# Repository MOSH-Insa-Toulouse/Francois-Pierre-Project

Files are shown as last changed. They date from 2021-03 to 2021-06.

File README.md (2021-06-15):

# Francois-Pierre-Project
## Projet capteur graphene
Projet de 4ème année Génie Physique, à l'INSA de Toulouse. Réalisation d'un capteur graphene de déformation. Le but est de mesurer la résistance et la tension du graphene sur une feuille de papier. Pour ce faire nous avons élaborer un capteur accessible à tous et simple d'utilisation sur arduino et App Inventor. Dans ce Git vous trouverez toute les ressources et information nécessaire pour comprendre le fonctionnement de notre capteur et pouvoir le réaliser chez vous.

## Sommaire

  - [1. Matériel requis](#1-Matériel-requis)
  - [2. Kicad](#2-Kicad)
      - [2.1 Création des empreintes et des composants](#21-Création-des-empreintes-et-des-composants)
      - [2.2 Création du PCB](#22-Création-du-PCB)
  - [3. Code Arduino](#3-code-arduino)
      - [3.1 Librairies utilisées](#31-Librairies-utilisées)
      - [3.2 Le code](#32-Le-code)
  - [4. Application Bluetooth](#4-application-Bluetooth)
  - [5. Banc de test](#5-Banc-de-test)
      - [5.1 Fonctionnement du banc](#51-Fonctionnement-du-banc)
      - [5.2 Code arduino](#52-Code-arduino)
  - [6. Datasheet](#6-datasheet)
  - [7. Contacte](#6-Contacte)

## 1. Matériel requis  

- Smartphone Androide 
- Carte Arduino Uno [info](https://www.arduino-france.com/review/arduino-uno/)
- Une plaque de cuivre pour shield. Ou bien des câbles de connexions
- Papier
- Crayon de papier
- Un module HC-05 (gestion du Bluetooth) [ici](https://fr.aliexpress.com/item/32496218488.html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)
- Un écran OLED [ici](https://www.google.com/aclk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)
- Un encodeur rotatif [ici](https://www.google.com/aclk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)
- Deux pince crocodile en cuivre
- Un transistor LTC1050 [ici](https://www.reichelt.com/fr/fr/amplificateurs-op-rationnels-unique-2-5-mhz-dil-8-ltc-1050-cn8-p10921.html) 

## 2. Kicad 

Kicad est un logiciel de conception pour l'électronique. Il permet de créer des schémas de circuit, visualiser des circuits en 3D, associer des empreintes au circuit. Dans notre cas, nous utilisons Kicad pour créer un shield pour notre carte Arduino Uno. Ce shield va nous permettre de monter nos composant directement sur la carte. Toute nos empreintes et plans de notre shield sont disponible dans [notre GIT](https://github.com/MOSH-Insa-Toulouse/Francois-Pierre-Project/tree/main/Shield)  

### 2.1 Création des empreintes et des composants

- Pour réaliser notre shield, nous avons dû créer une librairie d'empreinte pour nos composants. En effet ceux-ci n'étant pas disponible sur les librairies de Kicad nous avons donc créés des schémas et empreintes pour tous nos modules.

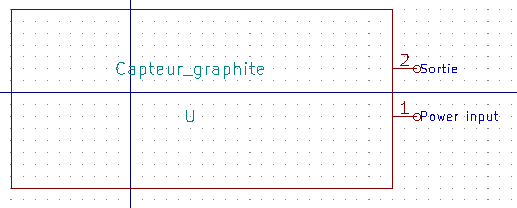
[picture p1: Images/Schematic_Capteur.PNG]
Capteur

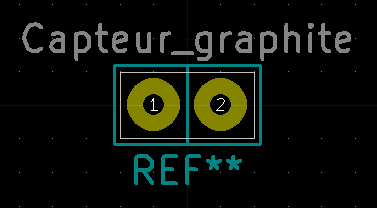
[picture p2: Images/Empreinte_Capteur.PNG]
Capteur

- *Capteur Graphite*

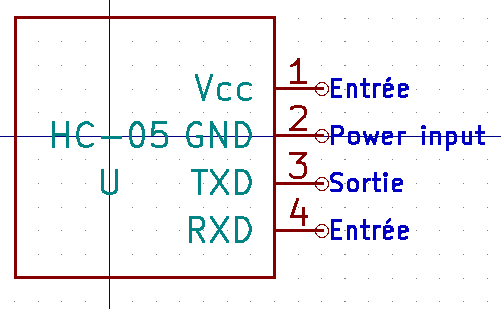
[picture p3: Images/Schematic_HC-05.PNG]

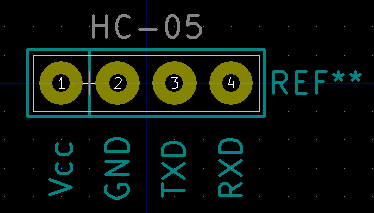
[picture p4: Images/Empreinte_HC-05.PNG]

- *HC-05*

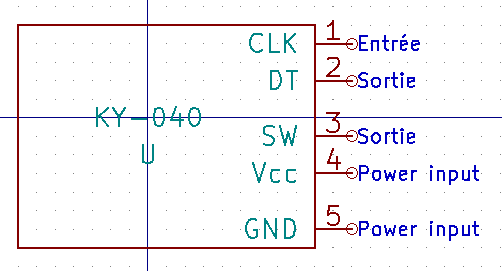
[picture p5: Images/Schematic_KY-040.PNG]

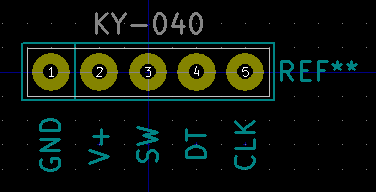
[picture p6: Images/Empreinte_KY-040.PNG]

- *Encodeur Rotatoire*

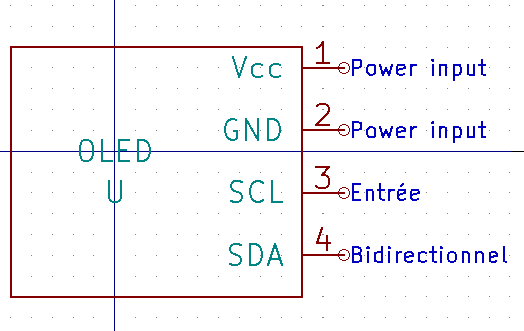
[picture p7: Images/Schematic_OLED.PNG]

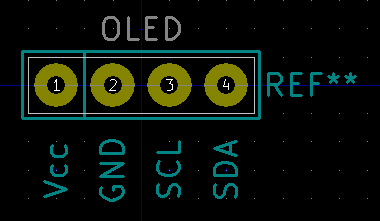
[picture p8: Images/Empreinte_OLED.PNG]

- *OLED*

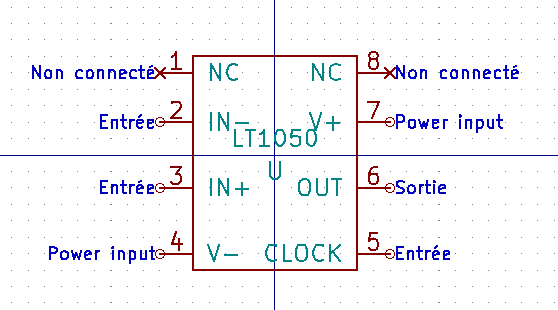
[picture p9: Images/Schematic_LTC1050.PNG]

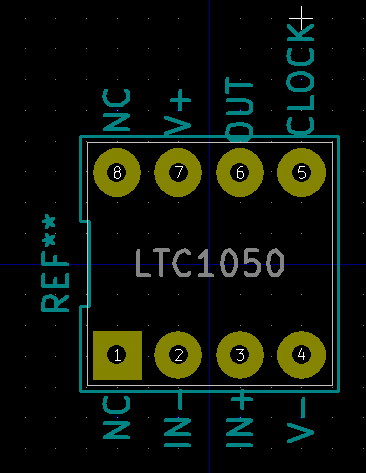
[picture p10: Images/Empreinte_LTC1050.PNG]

- *LTC1050*

### 2.2 Création du PCB

- Une fois les empreintes et les schématiques crées nous avons pu réaliser la schématique complète du circuit. Dans ce schéma vous pouvez retrouver nos modules ainsi que des composants éléctronique de base.

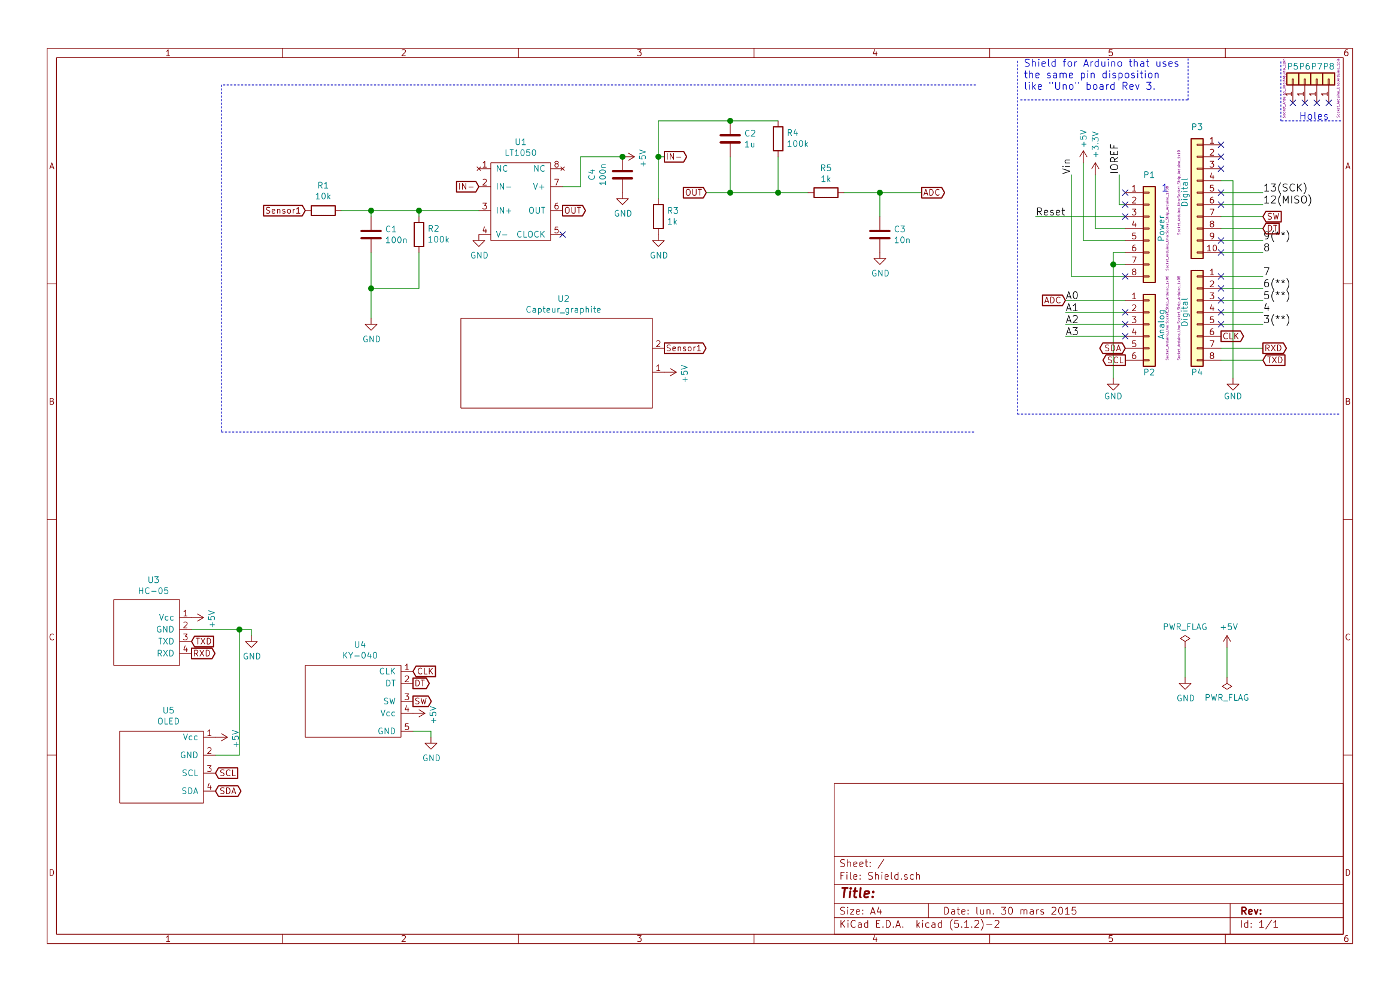
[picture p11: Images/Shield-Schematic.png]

- *Schéma de notre circuit*

- Une fois la schématique finis nous avons pu allouer à chaque composants (résistance, capacité...) une empreinte. Nous avons ensuite visualisé sur l'éditeur de circuit imprimé notre PCB. Nous avons donc organisé nos composant pour qu'il tiennent sur le shield et que nous puissons router correctement et sur chaque pin les différents modules.

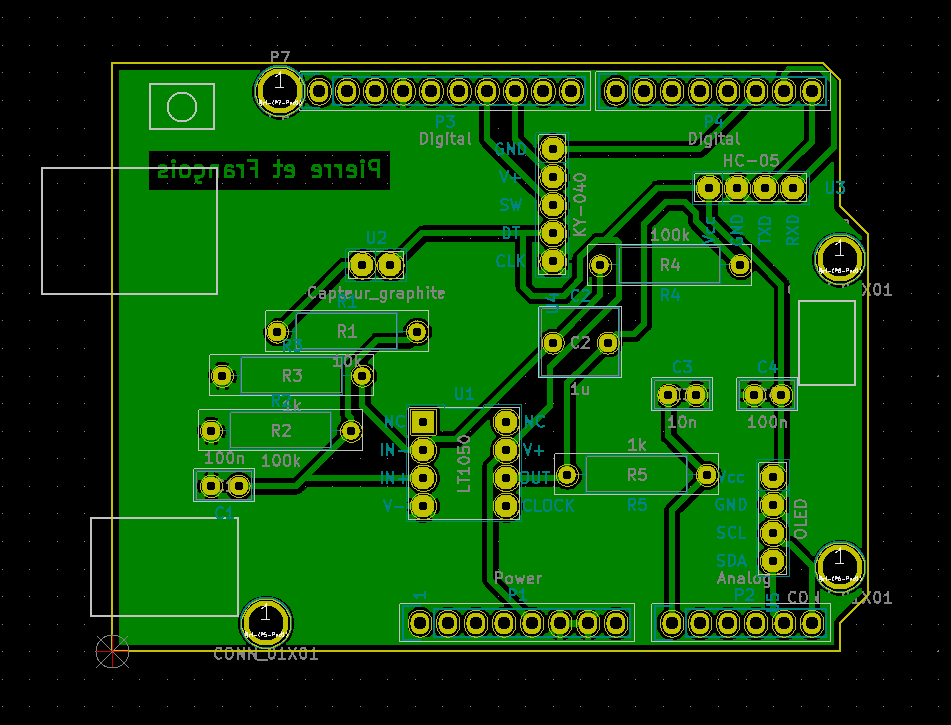
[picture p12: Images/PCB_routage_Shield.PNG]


- Pour être sur du résultat que nous voulions nous avons pu visulaiser sur Gerber notre shield en 3D avec les composant dessus, à l'execption des module bluetooth, de l'encodeur, du capteur et du LTC qui n'ont pas d'empreinte 3D.

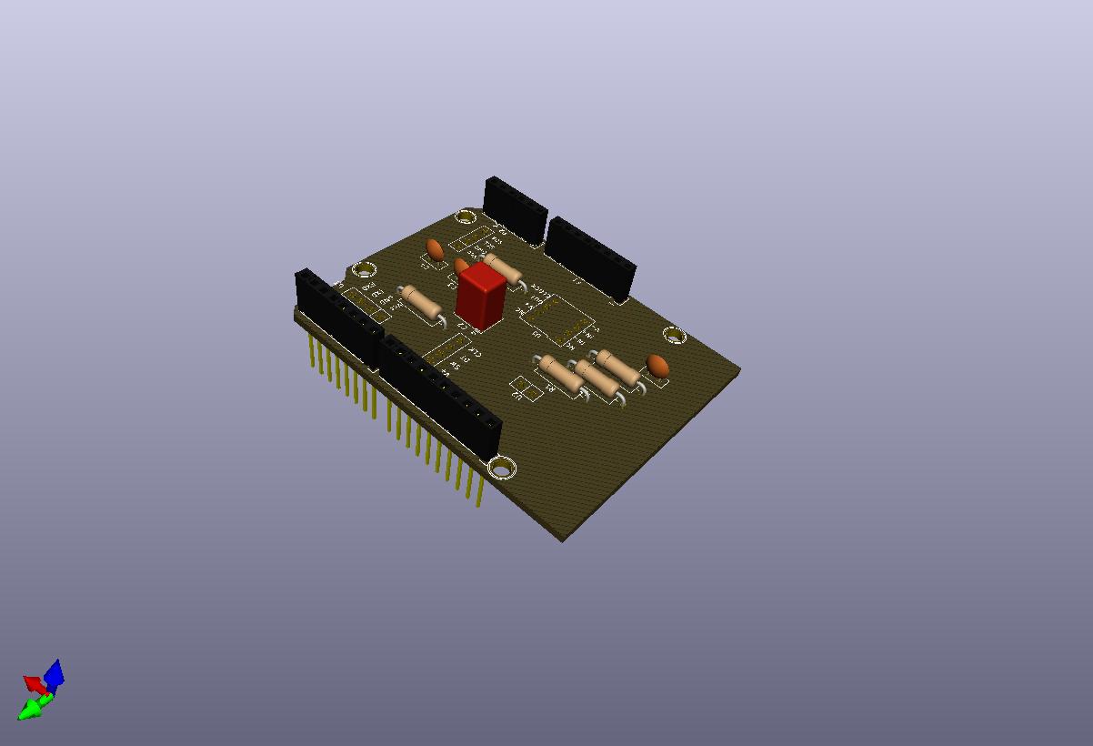
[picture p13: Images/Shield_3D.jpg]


## 3. Code Arduino

### 3.1 Librairies utilisées

- Pour réaliser notre capteur, nous utilisons [trois librairies](https://github.com/MOSH-Insa-Toulouse/Francois-Pierre-Project/tree/main/Libairies%20Arduino). 
- La librairie ["Adafruit_BusIO"](https://github.com/MOSH-Insa-Toulouse/Francois-Pierre-Project/tree/main/Libairies%20Arduino/Adafruit_BusIO) qui permet de gérer le connexions en I2C et SPI
- Les librairies ["Adafruit_GFX_Library"](https://github.com/MOSH-Insa-Toulouse/Francois-Pierre-Project/tree/main/Libairies%20Arduino/Adafruit_GFX_Library) et ["Adafruit_SSD1306"](https://github.com/MOSH-Insa-Toulouse/Francois-Pierre-Project/tree/main/Libairies%20Arduino/Adafruit_SSD1306)qui permet de gérer notre écran OLED.

### 3.2 Le code

- [Le code arduino](https://github.com/MOSH-Insa-Toulouse/Francois-Pierre-Project/tree/main/Code-Capteur-Graphite) permet de gérer le capteur. Il récupère sur le pin analogique A0 la valeur de la tension du capteur. Grace à une analyse du circuit électronique, nous pouvons déterminer la résistance en fonction de cette tension. Le code affiche sur un écran OLED différents menus en fonction de si l'on appuie ou non sur l'encodeur rotatoire. Il y a un delay de 5ms entre chaque lecture analogique.

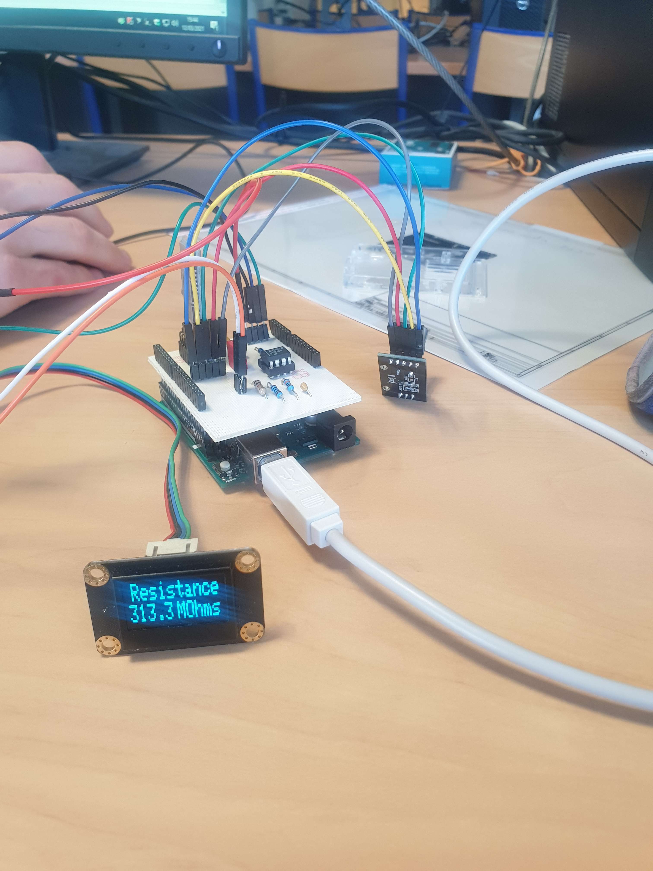
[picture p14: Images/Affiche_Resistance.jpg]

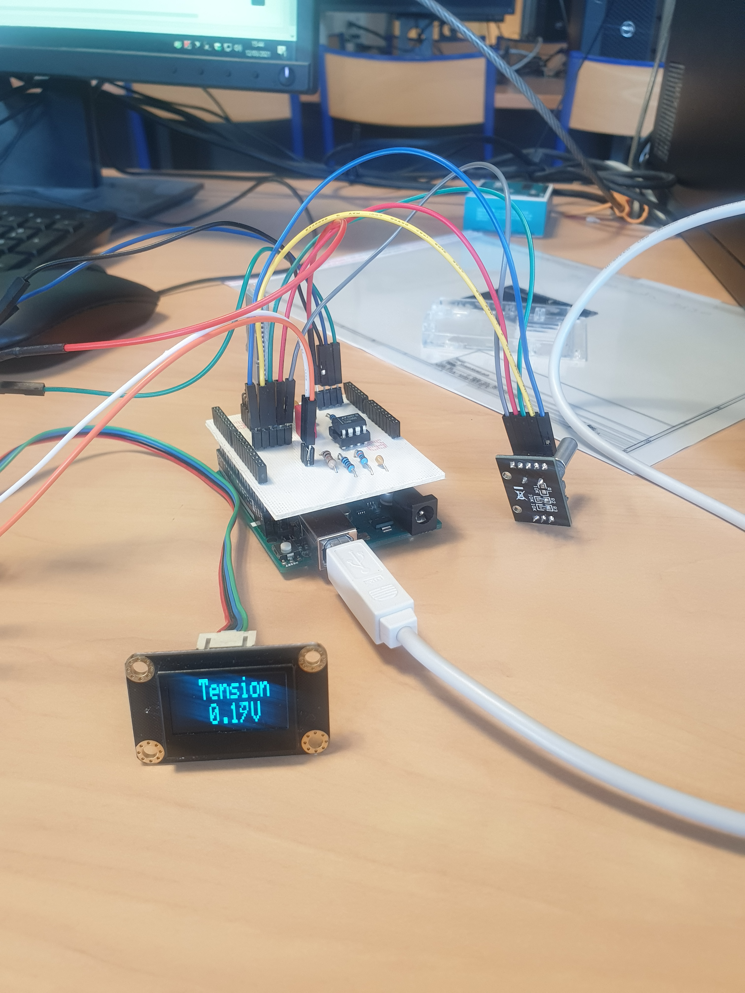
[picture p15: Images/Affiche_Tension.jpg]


## 4. Application Bluetooth

- [L'application](https://github.com/MOSH-Insa-Toulouse/Francois-Pierre-Project/blob/main/TP5.apk) permet de recevoir sur le téléphone la mesure de la résistance et de la tension délivré par le capteur. Nous affichons les deux donnés et nous traçons un graphique de la variation de résistance avec une échelle ajustable. La carte Arduino et plus précisément le module Bluetooth envoie un octet de donnée au téléphone via les pins TX et RX. Cet octet contient à la fois des valeurs de résistance et de tension séparés par de ",". Chaque doublet de valeurs est lui séparé par des ";". Notre téléphone reçois donc "49,0.39;35,0.60;70,0.37" avec d'abord la valeur de résistance puis une valeur de tension. Le téléphone sépare donc chaque valeur et les affiches. Notre application traite les données sur un intervalle de 100ms. 

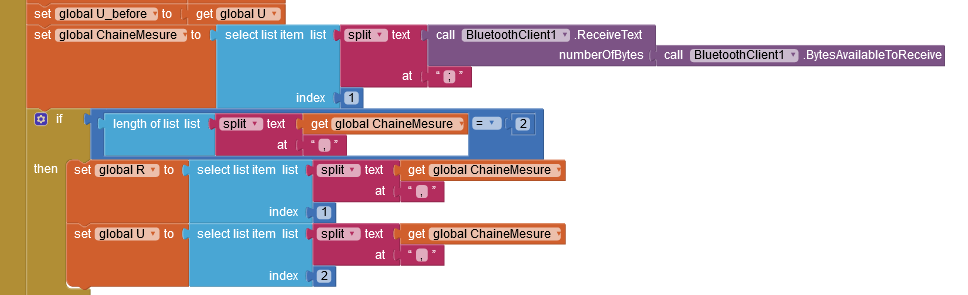
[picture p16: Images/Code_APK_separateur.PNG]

- *Code de l'application qui permet de séparer l'octet reçu et de séparer tension et résistance*

- Notre code a aussi une fonctionnalité qui enlève les variations trop importantes de résistance. En effet lors de nos tests notre téléphone recevait bien les valeurs affichées par le OLED, seulement nous avions aussi des valeurs intempestives qui ne correspondaient pas à une mesure (entre 1 et 9). Pour pallier ce problème, nous avons donc décider de ne pas prendre en compte les variations trop importantes.

- Pour finir nous avons rajouté une fonctionnalité qui permet à l'utilisateur de zoomer ou dezoomer sur le graphique.
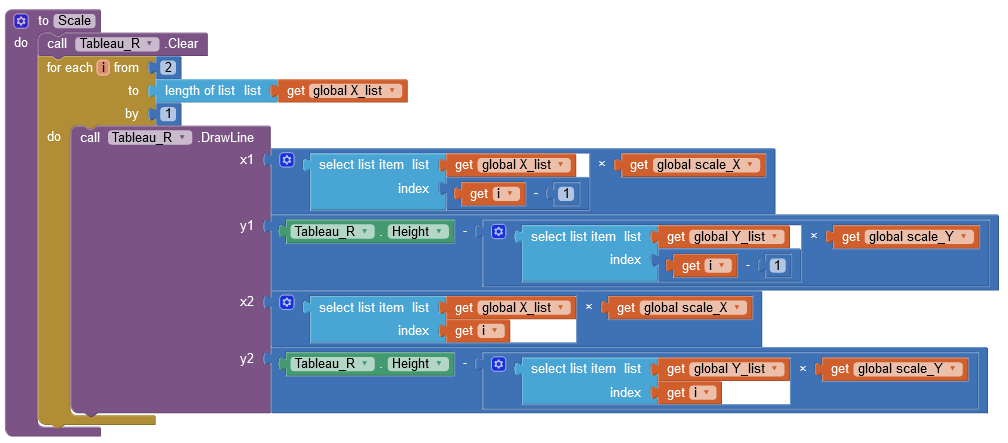
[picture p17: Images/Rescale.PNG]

- *Code APK permettant de Rescale le graphique*

- La face avant de notre application permet de choisir un module Bluetooth auquel se connecter (Cadre rouge), puis de régler l'échelle (bleu), de visualiser la variation de résistance (marron), et d'avoir les valeurs de résistance et tension en temps réelle (vert).
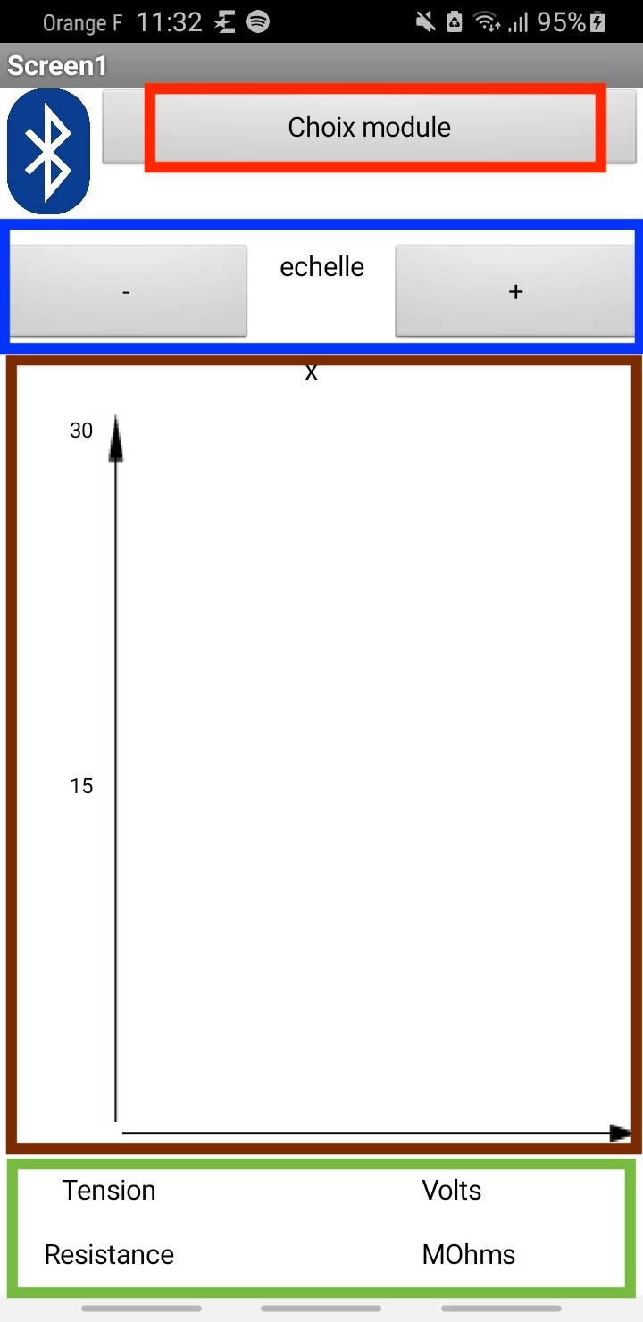
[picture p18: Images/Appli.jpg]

- *Face avant de notre application*

## 5. Banc de test

- Le banc de test est réalisé sur le logiciel de CAO FreeCad. Il nous est utile pour remplacer le banc de test initiale qui endommage et plie de manière irréversible la jauge de graphite. Le banc de test que nous avons imaginé permettrait donc de ré utiliser la même jauge plusieurs fois car celle-ci ne serait pas endommagé par les tests. Les fichier stl pour impression 3D sont [ici](https://github.com/MOSH-Insa-Toulouse/Francois-Pierre-Project/tree/main/Banc%20de%20test).

### 5.1 Fonctionnement du banc

- Le banc de test que nous avons imaginé permet de mesurer la déformation du capteur sans avoir à le toucher. Il est constitué de deux partie, le socle et la barre. Le servomoteur vient se positionner dans l'extrusion de la barre. Le disque présent sur l'autre côté vient lui se placer dans l'encoche du socle. Les pince crocodile ainsi que la jauge sont immobile grâce à l'encadrement dans lequel ils viennent s'insérer. Le servomoteur vient donc faire tourner la barre de bas en haut et nous récupérons les valeurs de résistances sur le terminal ou dans le fichier txt de notre téléphone.

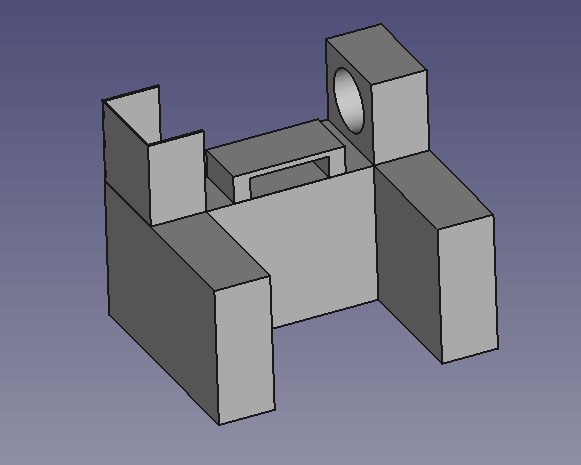
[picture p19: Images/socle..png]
- 
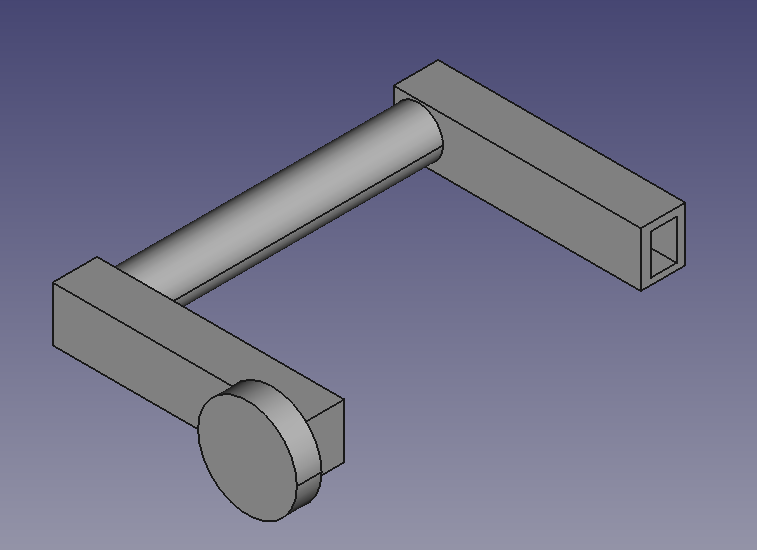
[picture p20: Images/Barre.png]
- 

- A l'inverse du banc de test initiale celui que nous avons imaginé n'a pas un rayon de courbure définis et connus. En revanche il est possible de connaitre le rayon de courbure avec la flèche F la distance S et R

### 5.2 Code arduino

- Le code arduino qui gèrent le banc de test permet d'afficher la résistance et la déformation en temps réelle. Il fait aussi s'activer le servomoteur, qui va bouger sur une rotation de 180 degrés. Cela nous permet de plier la jauge dans les deux sens. Étant donné que dans notre cas nous ne connaissons pas le rayon de courbure nous devons le calculer. Ceci est possible celons la manière suivante : 

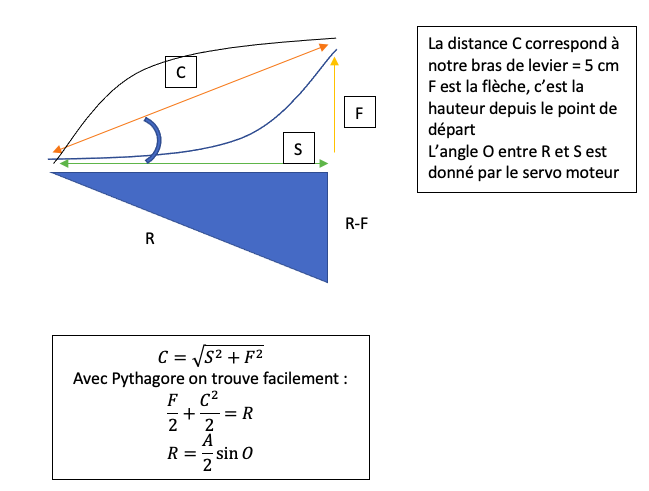
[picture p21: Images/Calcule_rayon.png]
- 

## 6. Datasheet

- [La datasheet](https://github.com/MOSH-Insa-Toulouse/Francois-Pierre-Project/blob/main/Datasheet.pdf) rédigé permet de comprendre les différentes caractéristiques de notre capteur. Veuillez la lire avant l'utilisation de celui-ci. 

## 7. Contacte

- Pour toute question concernant le capteur, l'application APK, le programme Arduino, le PCB ou pour tout complément d'information veuillez nous contacter par mail :
- Pierre CLARET pclaret@etud.insa-toulouse.fr
- François LEPETIT-AIMONT lepetit-@etud.insa-toulouse.fr

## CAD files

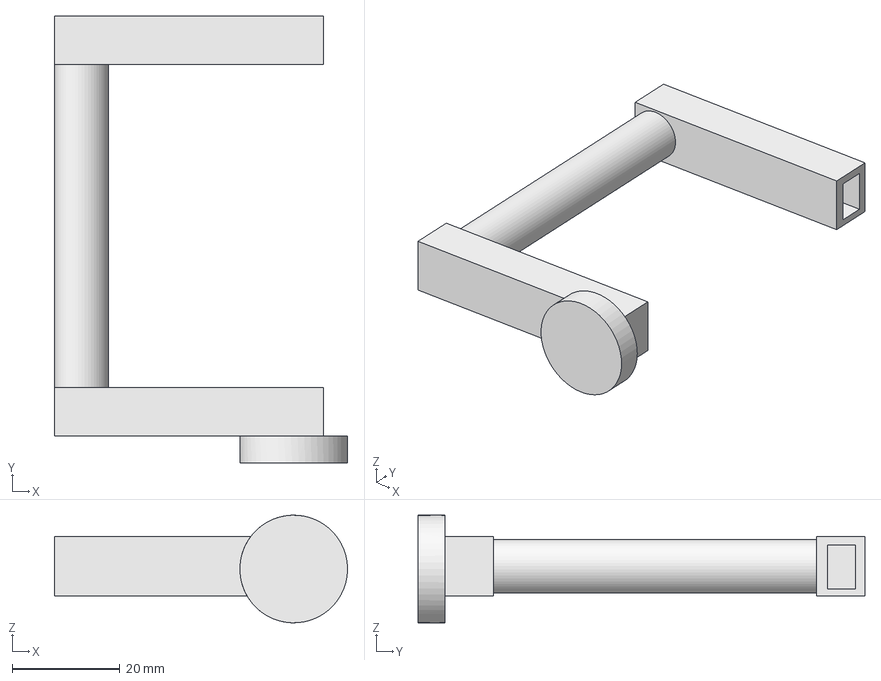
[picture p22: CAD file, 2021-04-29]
Banc de test/Barre.FCStd
54.4 x 83.0 x 20.0 mm

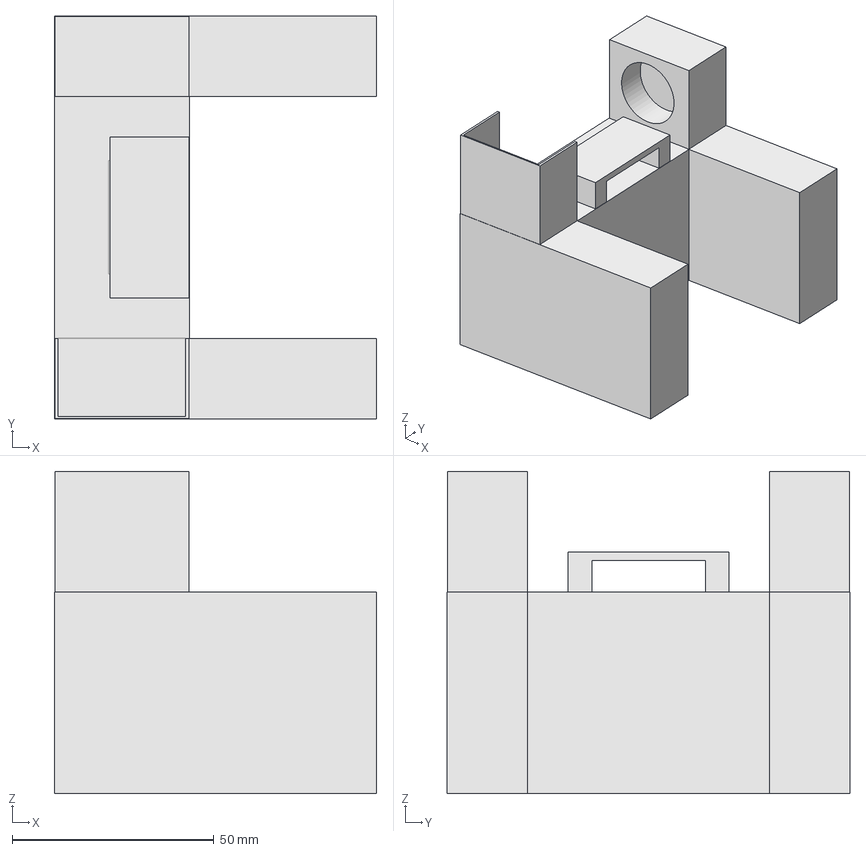
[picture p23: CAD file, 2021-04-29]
Banc de test/socle.FCStd
80.0 x 100.0 x 80.0 mm

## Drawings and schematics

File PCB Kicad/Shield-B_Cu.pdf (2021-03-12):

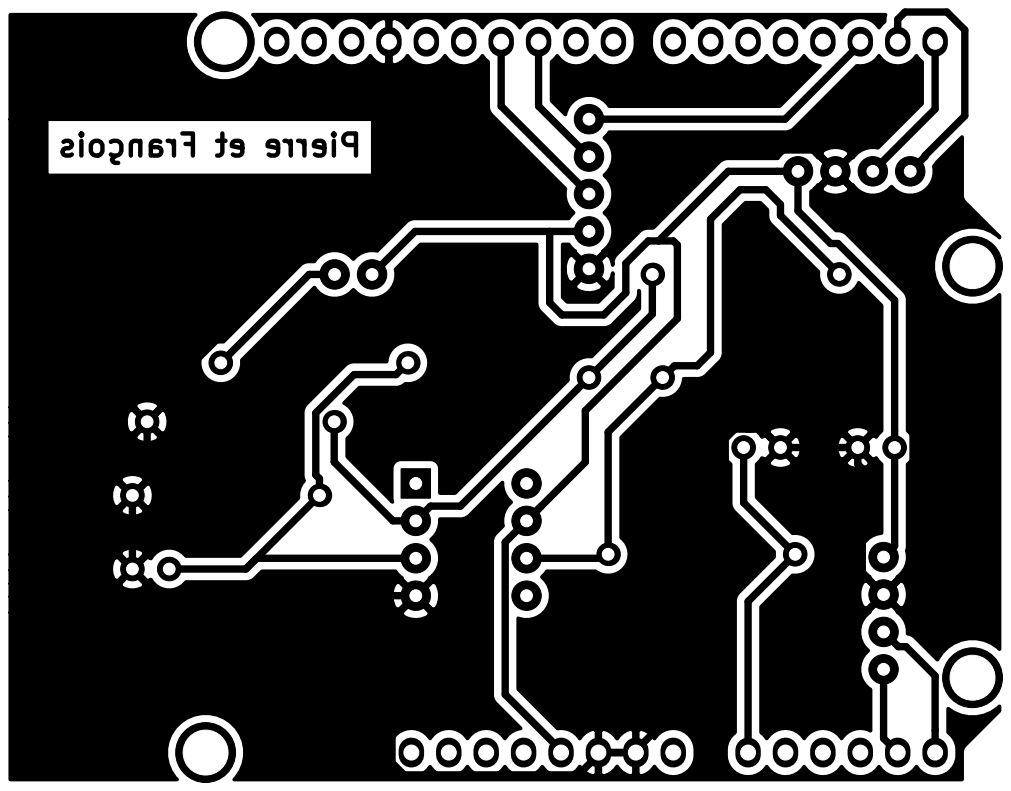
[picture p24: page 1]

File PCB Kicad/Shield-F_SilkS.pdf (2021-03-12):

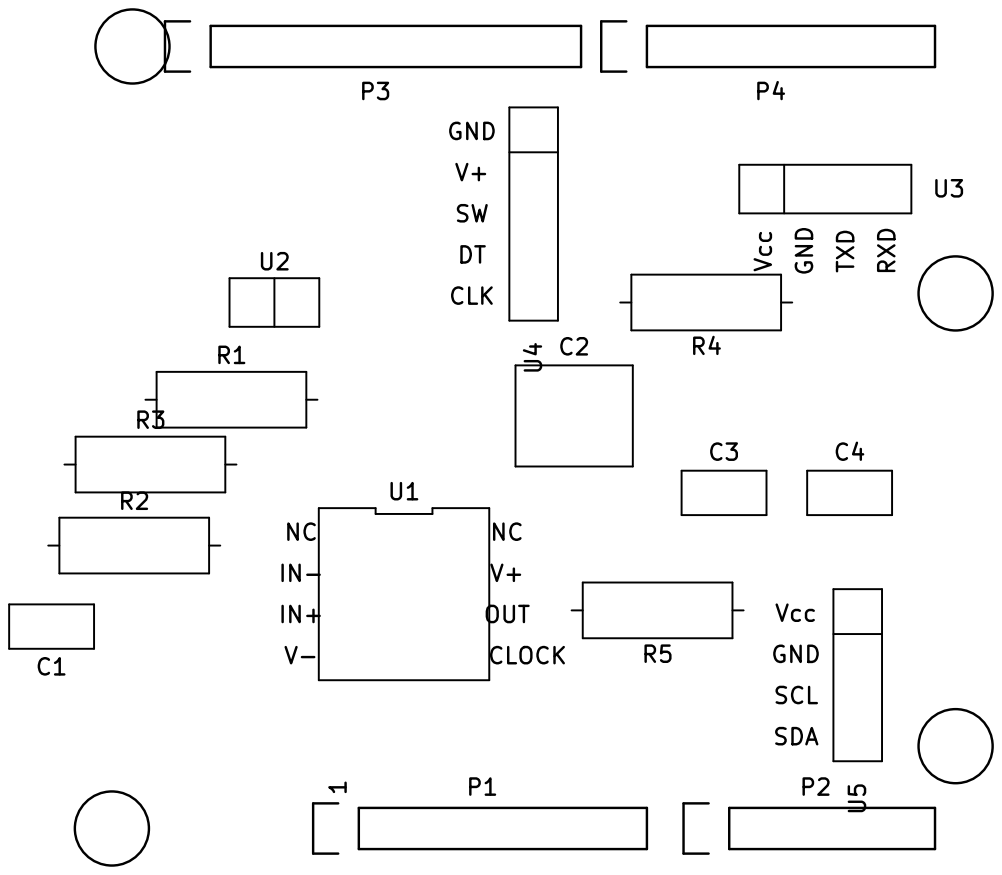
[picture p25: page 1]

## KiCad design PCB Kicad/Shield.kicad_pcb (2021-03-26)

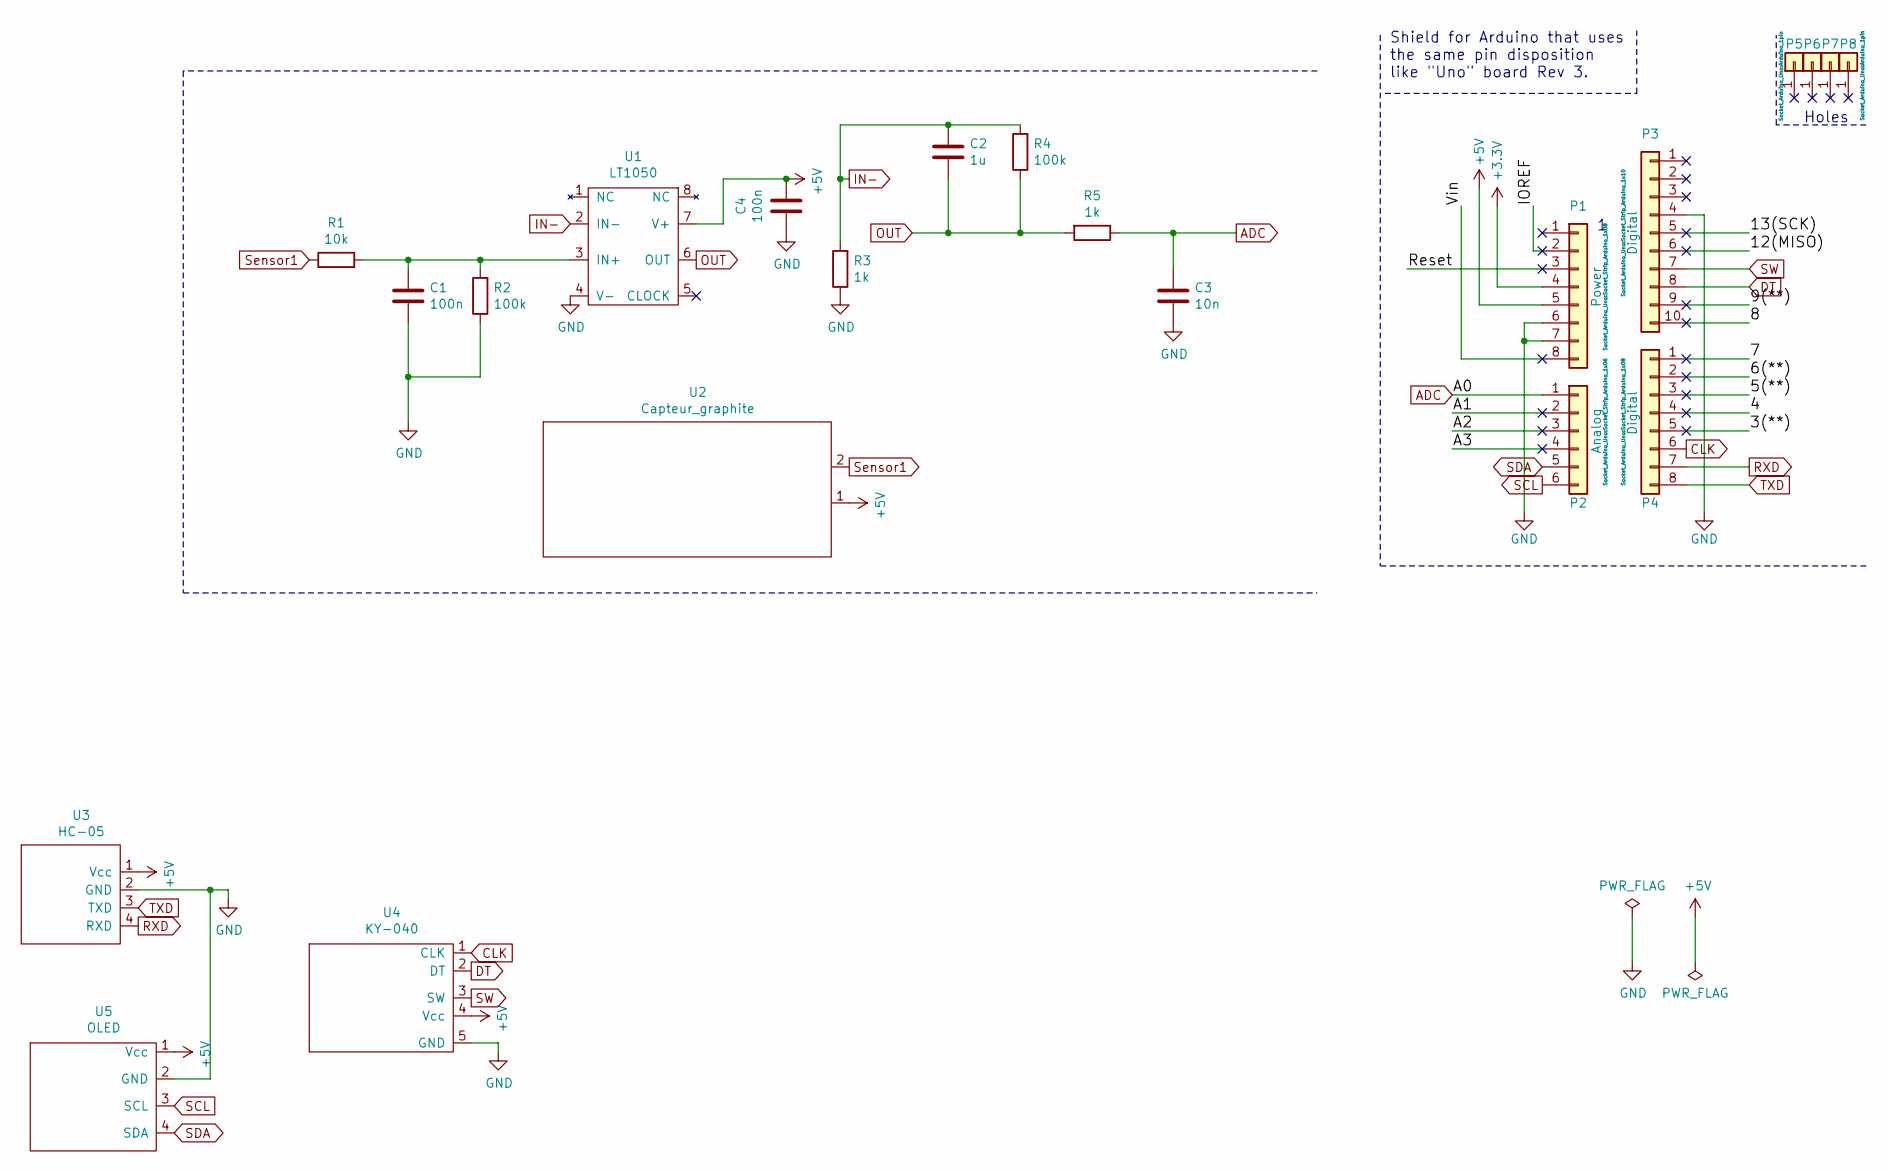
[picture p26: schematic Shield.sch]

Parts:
C1, C4: 100n; C_Disc_D5.0mm_W2.5mm_P2.50mm
C2: 1u; C_Rect_L7.0mm_W6.0mm_P5.00mm
C3: 10n; C_Disc_D5.0mm_W2.5mm_P2.50mm
P1: Power; Socket_Strip_Arduino_1x08
P2: Analog; Socket_Strip_Arduino_1x06
P3: Digital; Socket_Strip_Arduino_1x10
P4: Digital; Socket_Strip_Arduino_1x08
P5, P6, P7, P8: CONN_01X01; Arduino_1pin
R1: 10k; R_Axial_DIN0309_L9.0mm_D3.2mm_P12.70mm_Horizontal
R2, R4: 100k; R_Axial_DIN0309_L9.0mm_D3.2mm_P12.70mm_Horizontal
R3, R5: 1k; R_Axial_DIN0309_L9.0mm_D3.2mm_P12.70mm_Horizontal
U1: LT1050; LTC1050
U2: Capteur_graphite
U3: HC-05
U4: KY-040
U5: OLED

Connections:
+3V3: P1.4
+5V: C4.2, P1.5, U1.7 (V+), U2.1, U3.1 (Vcc), U4.4 (Vcc), U5.1 (Vcc)
/3(**): P4.5
/4: P4.4
/5(**): P4.3
/6(**): P4.2
/7: P4.1
/8: P3.10
/9(**): P3.9
/12(MISO): P3.6
/13(SCK): P3.5
/A1: P2.2
/A2: P2.3
/A3: P2.4
/IOREF: P1.2
/Reset: P1.3
/Vin: P1.8
ADC: C3.1, P2.1, R5.1
CLK: P4.6, U4.1 (CLK)
DT: P3.8, U4.2 (DT)
GND: C1.2, C3.2, C4.1, P1.6, P1.7, P3.4, R2.1, R3.1, U1.4 (V-), U3.2 (GND), U4.5 (GND), U5.2 (GND)
IN-: C2.1, R3.2, R4.2, U1.2 (IN-)
unnamed: C1.1, R1.2, R2.2, U1.3 (IN+)
OUT: C2.2, R4.1, R5.2, U1.6 (OUT)
RXD: P4.7, U3.4 (RXD)
SCL: P2.6, U5.3 (SCL)
SDA: P2.5, U5.4 (SDA)
SW: P3.7, U4.3 (SW)
Sensor1: R1.1, U2.2
TXD: P4.8, U3.3 (TXD)

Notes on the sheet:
Holes
Shield for Arduino that uses the same pin disposition like "Uno" board Rev 3.

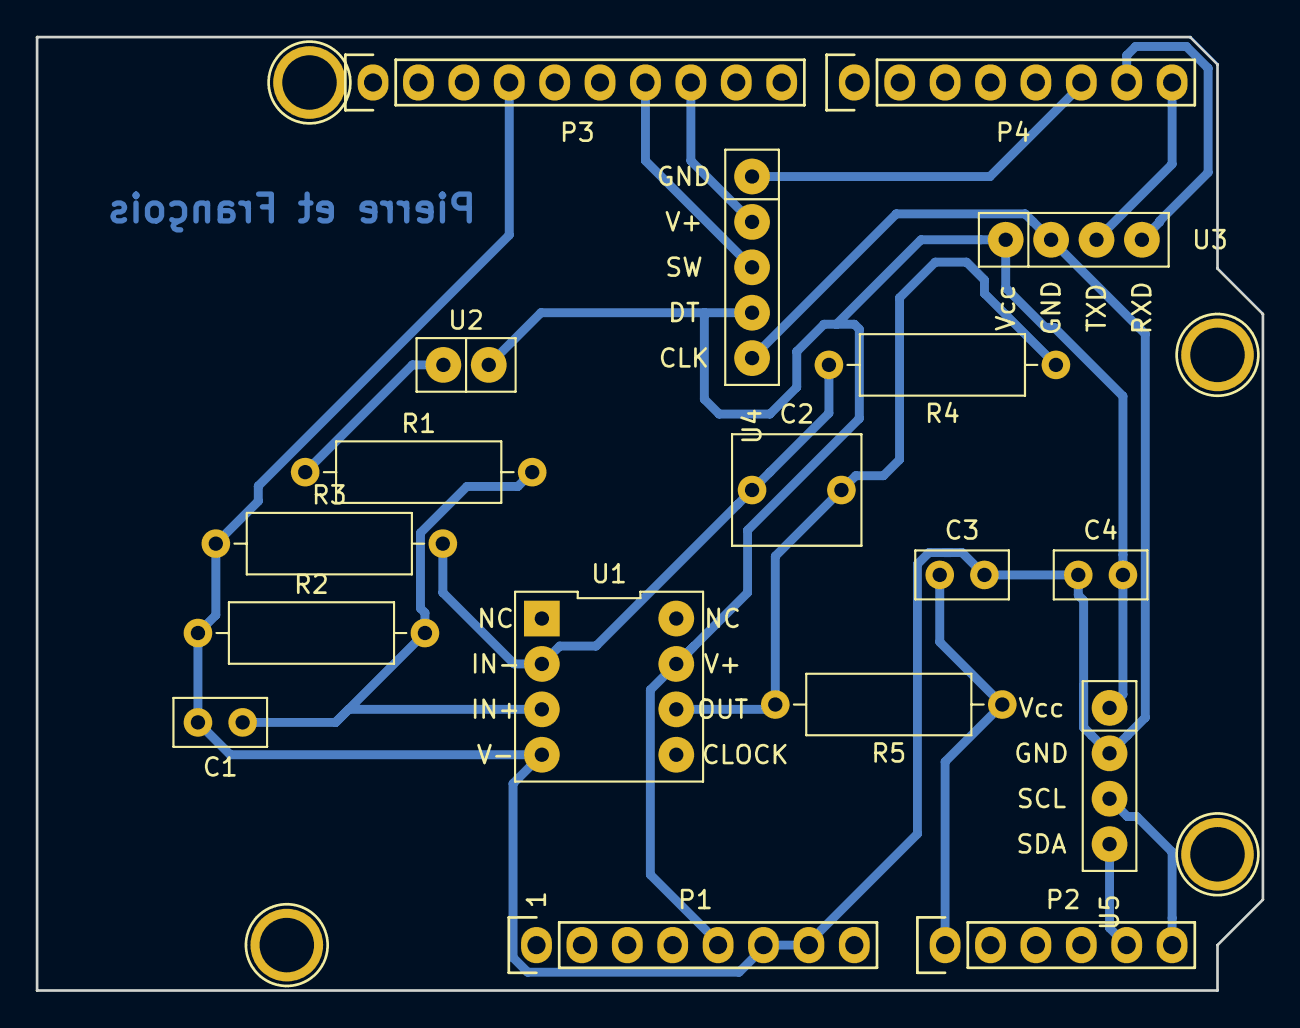
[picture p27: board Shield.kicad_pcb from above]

Board: 2 copper layers, 68.6 x 53.3 mm, 22 parts (0 on the bottom side), 14 nets.

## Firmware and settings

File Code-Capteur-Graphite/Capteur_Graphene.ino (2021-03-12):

#include <Adafruit_SSD1306.h>
#include <splash.h>
#include <Adafruit_GFX.h>
#include <Adafruit_GrayOLED.h>
#include <Adafruit_SPITFT.h>
#include <Adafruit_SPITFT_Macros.h>
#include <gfxfont.h>
#include <SoftwareSerial.h>
#include <SPI.h>
#include <Wire.h>



#define baudrate 9600

//HC-05
#define rxPin 1
#define txPin 0


//Capteur
#define analog_port 0

//Écran
#define SCREEN_ADDRESS 0x3C
Adafruit_SSD1306 display(-1);  //-1 car pas de pin reset

// Encodeur Rotatoire
#define clkPin 2
#define dtPin 10
#define swPin 11


double Voltage;
double resistance;
int menu = 0;
bool clkState  = LOW;
bool clkLast  = HIGH;
bool swState  = HIGH;
bool swLast  = HIGH;
int rotVal = 0;

//Retourne la position de l'encodeur
int readPos() {

  clkState = digitalRead(clkPin);
  if ((clkLast == LOW) && (clkState == HIGH)) {//rotary moving
    Serial.print("Rotary position ");
    if (digitalRead(dtPin) == HIGH) {
      rotVal = rotVal - 1;
      if ( rotVal < 0 ) {
        rotVal = 0;
      }
    }
    else {
      rotVal++;
      if ( rotVal > 10 ) {
        rotVal = 10;
      }
    }
    Serial.println(rotVal);
    delay(200);
  }
  clkLast = clkState;
  return rotVal;
}

//Retourne le nombre de fois ou l'on a appuyer sur l'encodeur
int readSw() { /* function readRotary */

  //gestion bouton
  swState = digitalRead(swPin);
  if (swState == LOW && swLast == HIGH) {
    menu++;
    delay(100);//debounce
  }
  swLast = swState;
  return menu;
}

//Affiche le menu principale

void Affichage_Menu() {
  display.clearDisplay();
  display.setTextSize(2);
  display.setTextColor(WHITE);

  display.setCursor(0, 0);
  display.println(F("Capteur"));
  display.setTextSize(1);
  display.setCursor(0, 17);
  display.println("Appuyez pour defiller");
  display.display();
}

//Affiche la tension

void Affichage_Tension (double u)
{

  display.clearDisplay();
  display.setTextSize(2);
  display.setTextColor(WHITE);

  display.setCursor(30, 0);
  display.println(F("Tension"));
  display.setCursor(40, 17);
  display.println(u);
  display.setCursor(90, 17);
  display.println(F("V"));
  display.display();
}

//Affiche la resistance

void Affichage_Resistance (double r)
{
  display.clearDisplay();
  display.setTextSize(2);
  display.setTextColor(WHITE);

  display.setCursor(5, 0);
  display.println(F("Resistance"));
  display.setCursor(0, 17);
  display.println(r, 1);
  display.setCursor(65, 17);
  display.println(F("MOhms"));
  display.display();
}



void setup()
{
  //Mode des pin de l'encodeur rotatoir
  pinMode(clkPin, INPUT);
  pinMode(dtPin, INPUT);
  pinMode(swPin, INPUT_PULLUP);

  //Ouverture des ports
  pinMode(rxPin, INPUT);
  pinMode(txPin, OUTPUT);
  Serial.begin(baudrate);
  display.begin(SSD1306_SWITCHCAPVCC, SCREEN_ADDRESS);
  display.clearDisplay();
  Affichage_Menu();//Affiche du menu principale
}



void loop()
{
  display(SSD1306_SETCONTRAST);                   // 0x81
  ssd1306_command(0x8F);
  Voltage = analogRead(analog_port) * 5.0 / 1024.0; //Tension sur 5V et 8bits
  resistance = (1 + 100) * 100000 * (5 / Voltage) - 100000 - 10000;//Calcule de la résistance
  Serial.print(resistance / 1000000); //envoie de la valeur de la résistance par le module bluetooth
  Serial.print(",");//séparateur entre la valeur de tension et de résistance
  Serial.print(Voltage);//envoie de la valeur de la tension par le module bluetooth
  Serial.print(";");//séparateur entre 2 mesures

  /*Dès qu'on appuie sur l'encodeur on bascule sur l'affichage tension ou résistance
    Un nombre pair d'appuie on affiche la résistance, un nombre impaire la tension*/
  if (!(readSw() == 0)) {
    if (readSw() % 2 == 0) {
      Affichage_Resistance(resistance / 1000000);
    } else if (readSw() % 2 == 1) {
      Affichage_Tension (Voltage) ;
    }
  }

  display.clearDisplay();
  delay(5);

}

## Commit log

2021-02-05 Création de dossier Arduino et Kicad
2021-03-26 Ajout d'images et datasheet
    [Shield.kicad_pcb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]
2021-03-28 Kicad (PCB, routage...)
    [Shield.kicad_pcb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]
2021-03-28 Code Arduino du capteur
2021-03-28 Librairies Arduino
2021-04-29 Ajout banc de test
    [Barre.FCStd, socle.FCStd]
2021-04-30 banc de test
2021-06-15 Correction des fautes (mais pas toutes j'en ai peur...)
